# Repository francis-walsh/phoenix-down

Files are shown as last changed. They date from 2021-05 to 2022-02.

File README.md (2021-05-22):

# phoenix-down



Phoenix Down is a PWM-controlled hot plate that regulates the temperature of your morning coffee. A 12V 2A voltage source is regulated by a buck converter to deliver a maximum of 24W to the array of power resistors, heating the board to a specified temperature monitored by a thermistor. The design uses a schmitt trigger, astable multivibrator, and a thermistor to configure the duty cycle of the PWM.

The computer has population options for different thermistors and voltage references for configuring the thermistor voltage threshold.

Rev 1 schematic
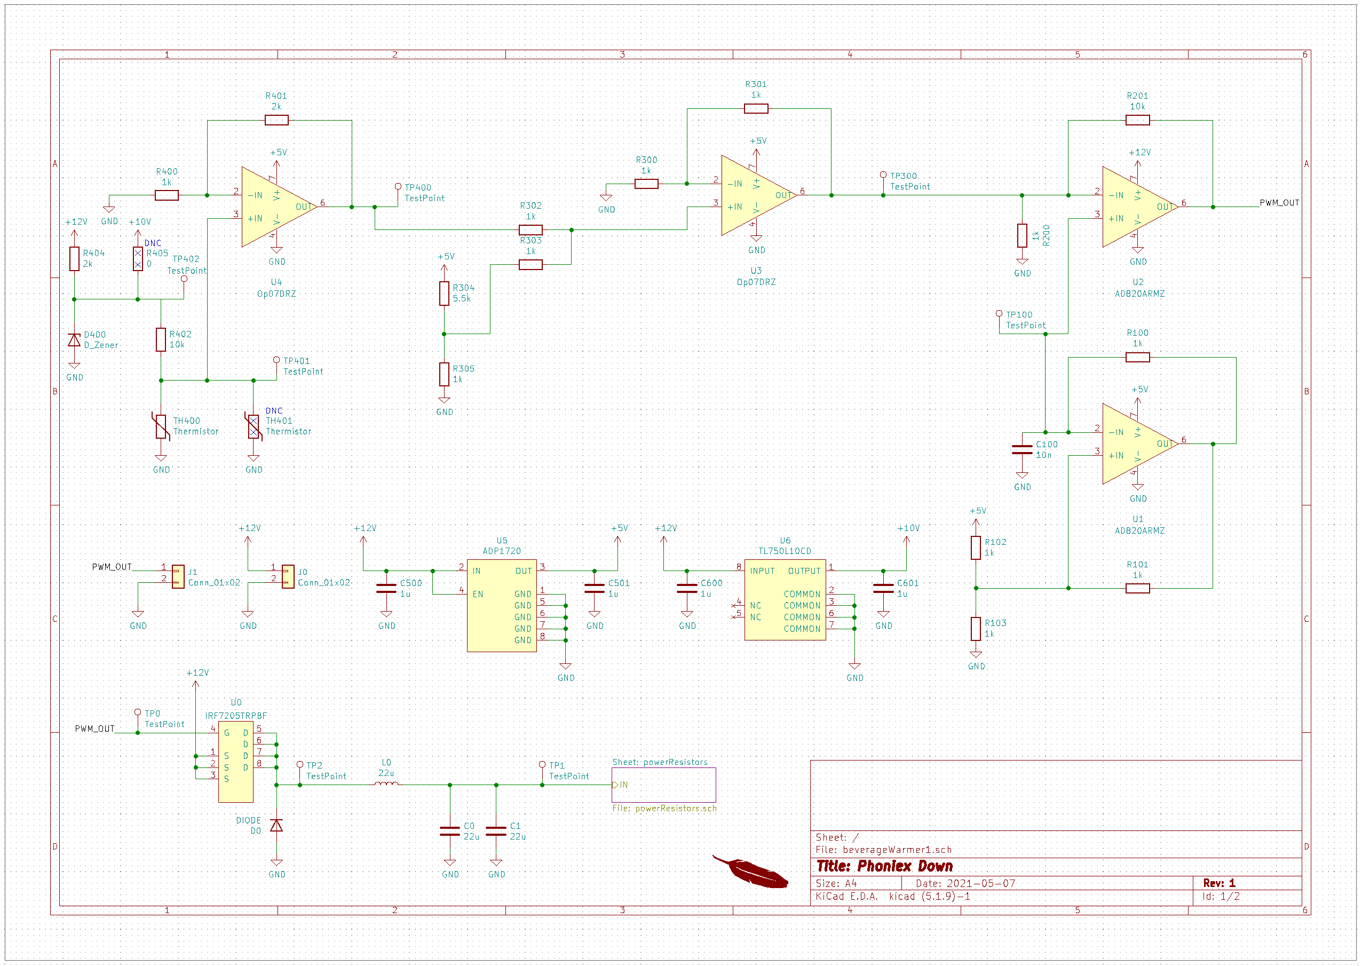
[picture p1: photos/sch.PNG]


Rev 1 TLspice simulation
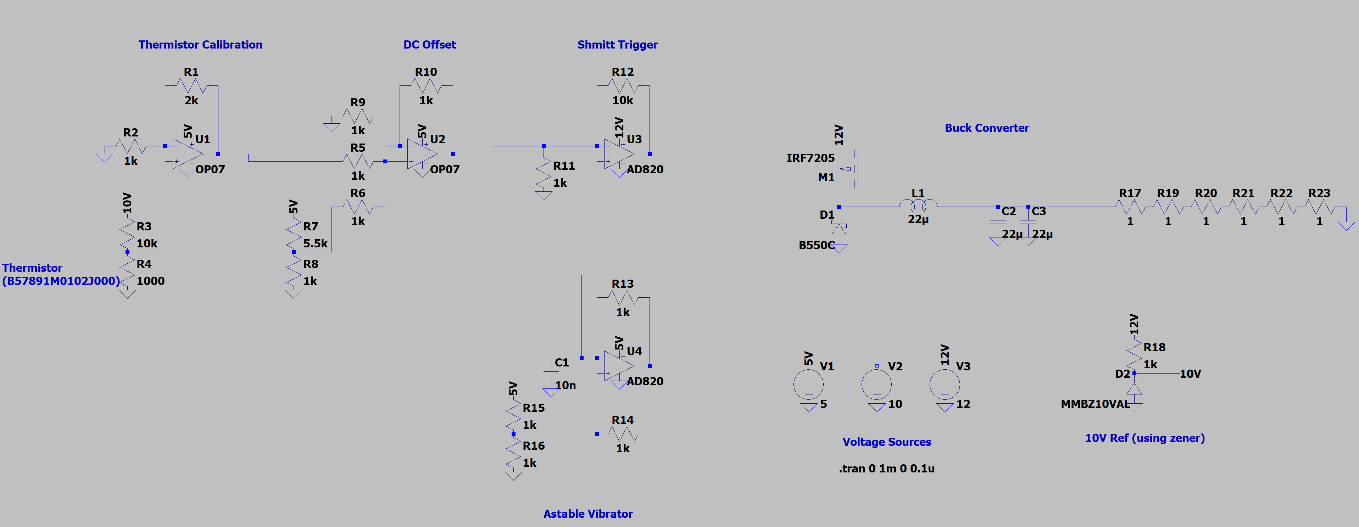
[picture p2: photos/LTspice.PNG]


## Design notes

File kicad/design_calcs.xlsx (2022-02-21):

Thermistor Properties
Parameter | Value | Unit
Standard Res | 10000 | Ohm
Beta | 3380 |  | Temp © | Temp (K) | Resistance (Ohm) | Low Res Parll. Combo (Ohm) | Divider Output (V) | ADC reading (Decimal) | Step For 2 deg change (V) | Temp Approx in Code © | Error %
Ref Temp | 25 | C | 20 | 293.15 | 12133.17001 | 5481.894371 | 2.132807912 | 2647.267033 |  | 20 | -7.105427358e-14
Ref Temp | 298.15 | K | 22 | 295.15 | 11221.29948 | 5287.753226 | 2.105466363 | 2613.330371 | 0.02734154872 | 21.61731737 | 1.739466488
Divider Properties |  |  | 24 | 297.15 | 10388.88114 | 5095.365983 | 2.077078143 | 2578.094568 | 0.02838822029 | 23.29654785 | 2.931050635
Parameter | Value | Unit | 26 | 299.15 | 9628.131096 | 4905.271444 | 2.047671086 | 2541.594173 | 0.02940705684 | 25.03604492 | 3.707519547
High Res | 3000 | Ohm | 28 | 301.15 | 8932.106405 | 4717.96757 | 2.017278881 | 2503.870999 | 0.03039220553 | 26.83381587 | 4.164943333
Low Res | 10000 | Ohm | 30 | 303.15 | 8294.606244 | 4533.908045 | 1.985940957 | 2464.973987 | 0.03133792423 | 28.68752832 | 4.374905609
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

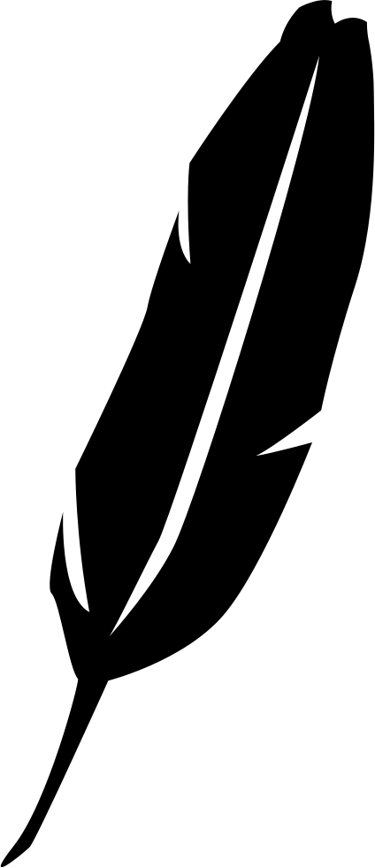
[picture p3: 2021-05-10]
kicad/downFeather/SeekPng.com_feather-vector-png_1046109.png

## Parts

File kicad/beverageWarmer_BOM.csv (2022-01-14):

Item | Qty | Reference(s) | Value | Digi | Have | Power | Tolerance | Voltage
1 | 30 | C1, C5, C6, C7, C8, C9, C15, C16, C19 | 1u | 445-6931-1-ND |  |  |  | 16V
2 | 25 | C2, C3, C10, C11, C12, C13, C14, C17, C18, C20 | 0.1u | 1276-1019-1-ND |  |  |  | 16V
3 | 5 | C4 | 10u | 1276-6641-1-ND |  |  |  | 6.3V
4 | 10 | D1, D5, D6 | V3FL45 | V3FL45HM3/HGICT-ND
5 | 4 | D2 | 5.6V | DDZ5V6BDICT-ND
6 | 4 | D3 | RED | 754-1123-1-ND
7 | 4 | D4 | GREEN | 754-1357-1-ND
8 | 10 | F1 | 3A | P15118CT-ND
9 | 4 | FB1 | FB | 490-1015-1-ND
10 | 2 | J1 | POWER | WM1860-ND
11 | 2 | J2 | CAN_CONN | WM1860-ND
12 | 3 | J3 | SWD | S9015E-03-ND
13 | 1 | J4 | THERM_CONN | WM1860-ND
14 | 3 | L1 | 68uH | SRR1260-560MCT-ND
15 | 9 | Q1, Q4 | Q_PMOS_DGS | SISS05DN-T1-GE3CT-ND
16 | 40 | R1, R3, R4, R5, R6, R7, R11, R12, R14, R15, R16, R17, R18, R20, R27, R29 | 1k | RMCF0603JJ1K00CT-ND |  |  | 1%
17 | 10 | R2, R19, R28 | 3k | RMCF0603FT3K00CT-ND |  |  | 1%
18 | 10 | R8 | 270 | A130470CT-ND |  | 1/4W
19 | 10 | R9 | 30 | 2019-RK73H2ATTD30R0FCT-ND |  | 1/4W
20 | 10 | R10, R25 | 10 | A130079CT-ND
21 | 10 | R13 | 120 | A129677CT-ND
22 | 10 | R21 | 10k | RMCF0603FT1K00CT-ND |  |  | 1%
23 | 10 | R22, R23, R24, R26 | 0 | 2019-RK73Z1JTTDCT-ND
24 | 20 | R30, R31, R32, R33, R34, R35 | 1 | A143800CT-ND
25 | 2 | SW1 | RESET | SW1020CT-ND
26 | 2 | SW2 | USER | SW1020CT-ND
27 | 3 | U1 | STM32F103TBU | 497-18758-1-ND | Yes
28 | 3 | U2 | MIC5283-3.3ML-TR | MIC5283-3.3YML-CT-ND | Yes
29 | 5 | U3 | Op07DRZ | OP07DRZ-ND | Yes
30 | 10 | U4 | TL391B | 296-TL391BIDBVRCT-ND
31 | 3 | U5 | SN65HVD232 | 296-12282-5-ND | Yes
32 | 10 | U6 | MCP1402T-E | MCP1402T-E/OTCT-ND

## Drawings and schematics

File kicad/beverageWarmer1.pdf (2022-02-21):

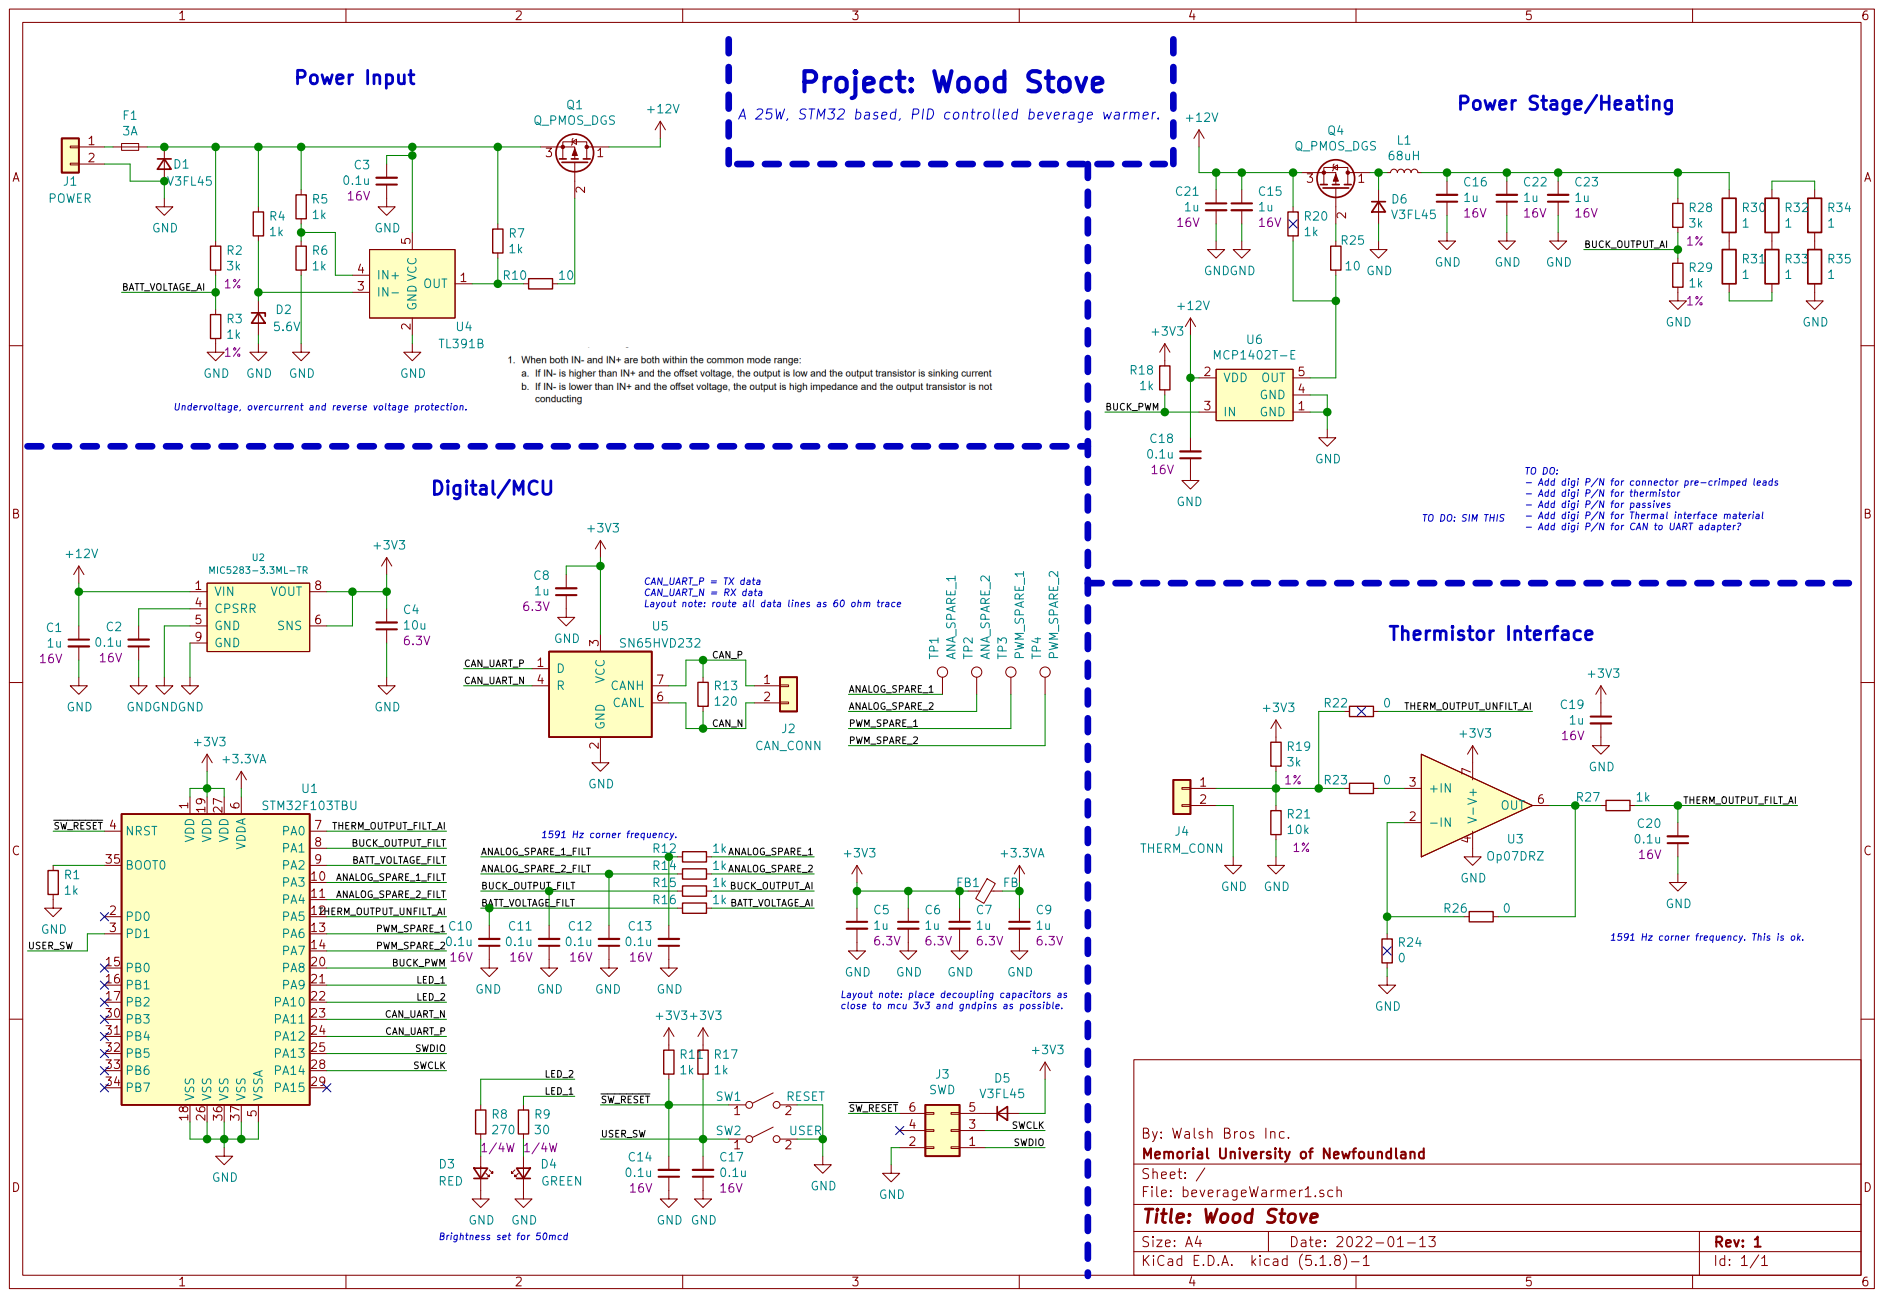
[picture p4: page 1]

1591 Hz corner frequency. This is ok. 1591 Hz corner frequency. Power Input

Layout note: route all data lines as 60 ohm trace Project: Wood Stove

TO DO: SIM THIS Digital/MCU

TO DO: - Add digi P/N for connector pre-crimped leads

- Add digi P/N for thermistor - Add digi P/N for passives - Add digi P/N for Thermal interface material - Add digi P/N for CAN to UART adapter?

By: Walsh Bros Inc. 1

1 PA3 10 PA4 11 PA5 12 PA6 13 PA7 14 PB0 15 PB1 16 PB2 17 VSS 18 VDD 19 PD0 2 PA8 20 PA9 21 PA10 22 PA11 23 PA12 24 PA13 25 VSS 26 VDD 27 PA14 28 PA15 29 PD1 3 PB3 30 PB4 31 PB5 32 PB6 33 PB7 34 BOOT0 35 VSS 36 VSS 37 NRST 4 VSSA

Layout note: place decoupling capacitors as close to mcu 3v3 and gndpins as possible.

File: beverageWarmer1.sch Sheet: / Memorial University of Newfoundland

Id: 1/1 Title: Wood Stove

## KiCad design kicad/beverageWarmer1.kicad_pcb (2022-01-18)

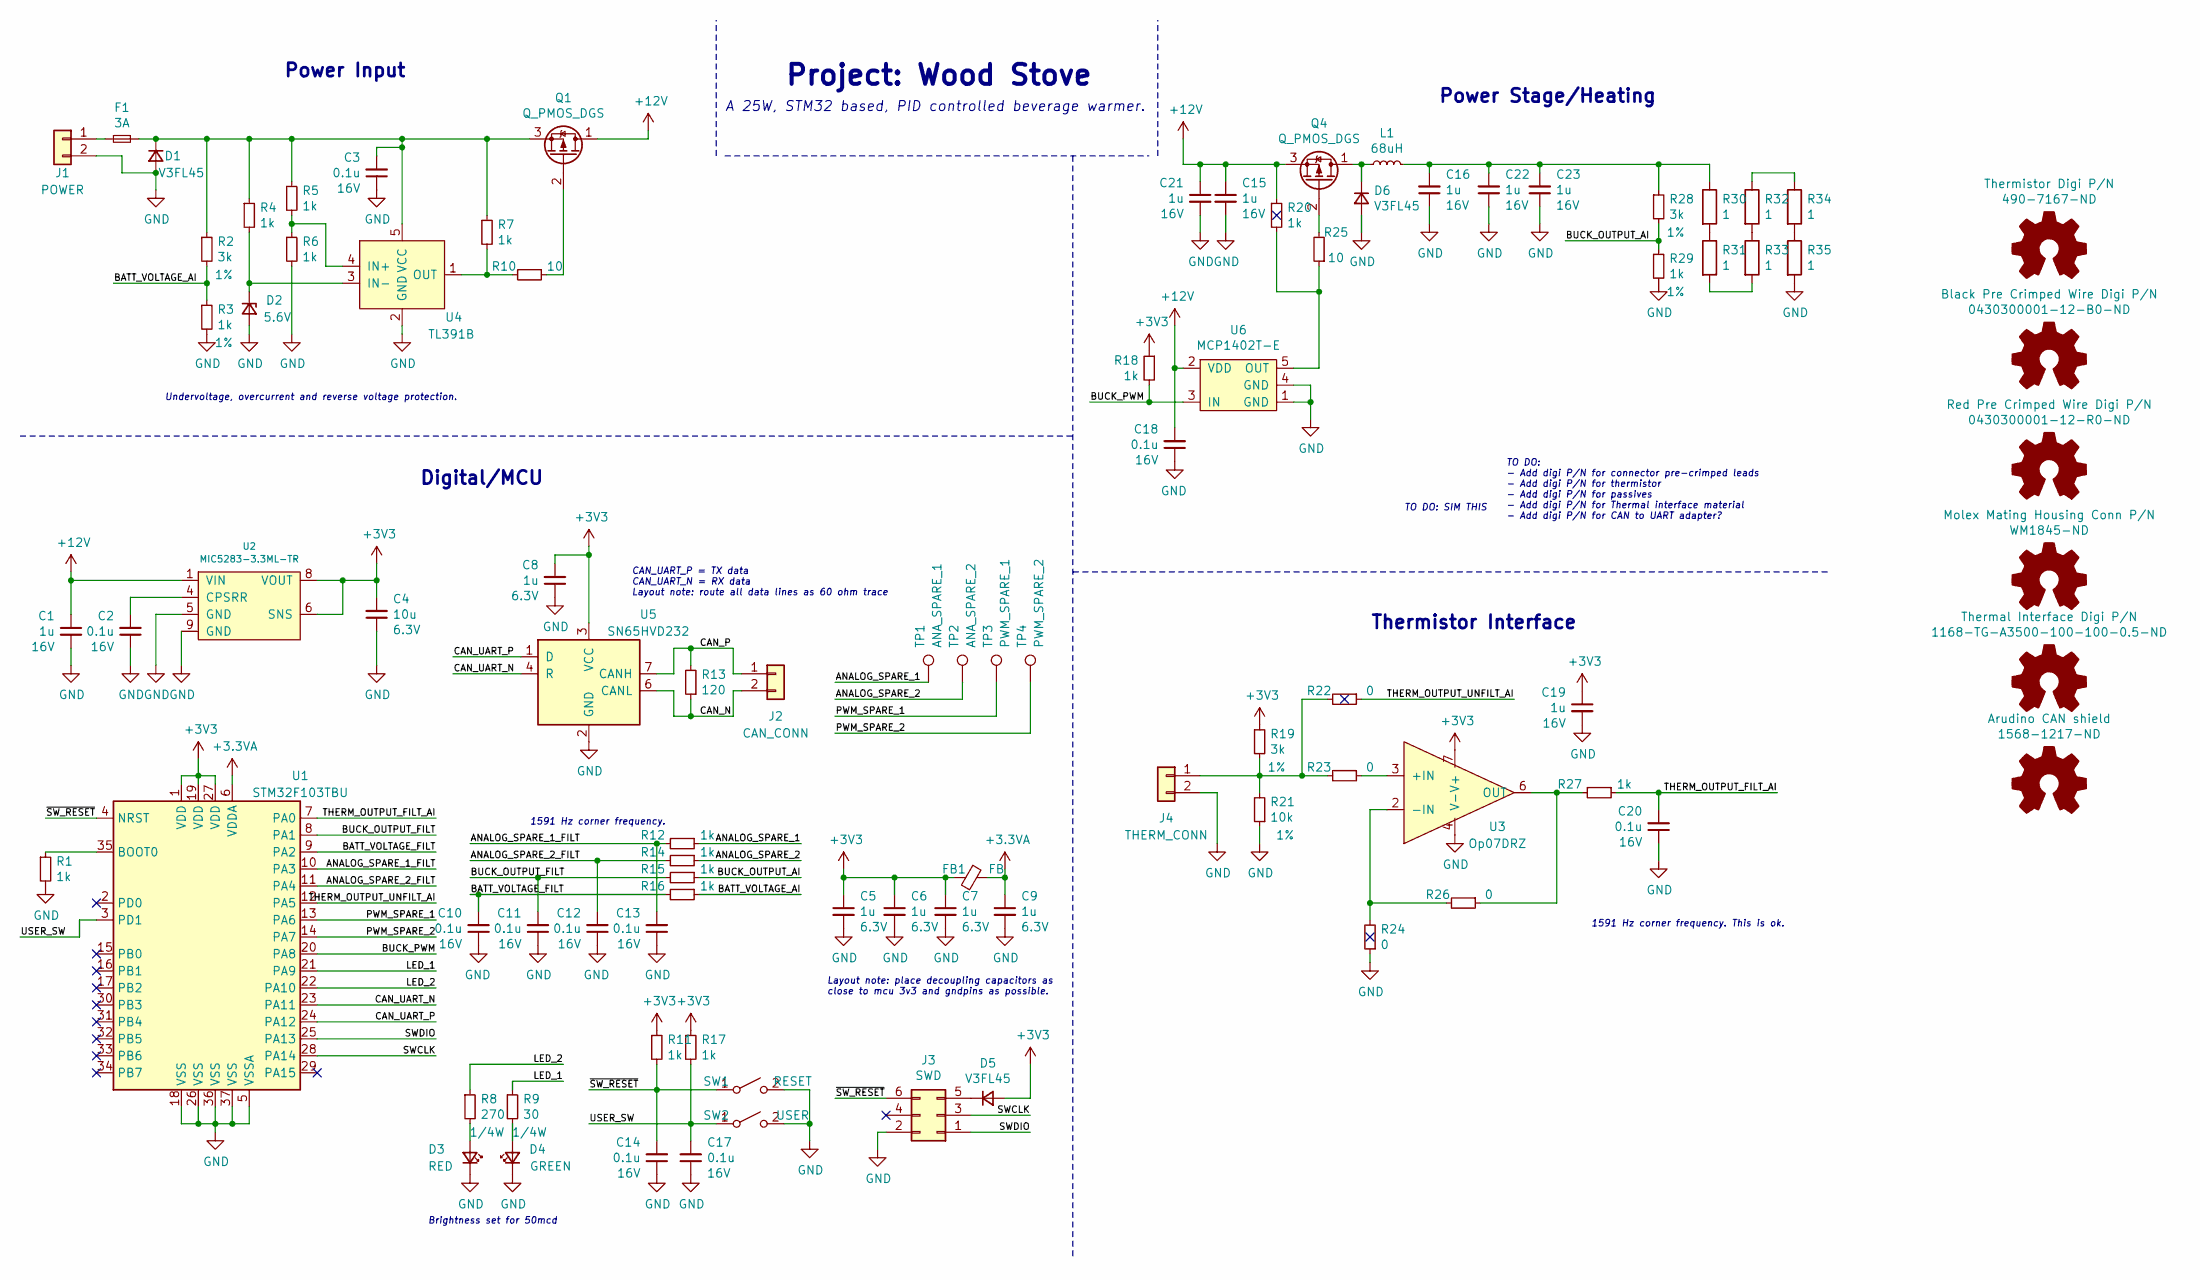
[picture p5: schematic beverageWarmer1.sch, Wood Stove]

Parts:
C1, C15, C16, C19, C21, C22, C23: 1u; C_0603_1608Metric; Voltage 16V; Digi 445-6931-1-ND
C2, C3, C10, C11, C12, C13, C14, C17, C18, C20: 0.1u; C_0603_1608Metric; Voltage 16V; Digi 1276-1019-1-ND
C4: 10u; C_1206_3216Metric; Voltage 6.3V; Digi 1276-6641-1-ND
C5, C6, C7, C8, C9: 1u; C_0603_1608Metric; Voltage 6.3V
D1, D5, D6: V3FL45; D_SMF; Digi V3FL45HM3/HGICT-ND
D2: 5.6V; D_SOD-123; Digi DDZ5V6BDICT-ND
D3: RED; LED_0603_1608Metric; Digi 754-1123-1-ND
D4: GREEN; LED_0603_1608Metric; Digi 754-1357-1-ND
F1: 3A; Fuse_0603_1608Metric; Digi P15118CT-ND
FB1: FB; L_0603_1608Metric; Digi 490-1015-1-ND
J1: POWER; Molex_Micro-Fit_3.0_43650-0200_1x02_P3.00mm_Horizontal; Digi WM1860-ND
J2: CAN_CONN; Molex_Micro-Fit_3.0_43650-0200_1x02_P3.00mm_Horizontal; Digi WM1860-ND
J3: SWD; PinSocket_2x03_P1.27mm_Vertical; Digi S9015E-03-ND
J4: THERM_CONN; Molex_Micro-Fit_3.0_43650-0200_1x02_P3.00mm_Horizontal; Digi WM1860-ND
L1: 68uH; L_Bourns_SRR1260; Digi SRR1260-560MCT-ND
Q1, Q4: Q_PMOS_DGS; SISS05DN-T1-GE3; Digi SISS05DN-T1-GE3CT-ND
R1, R4, R5, R6, R7, R11, R12, R14, R15, R16, R17, R18, R20, R27: 1k; R_0603_1608Metric; Digi RMCF0603JJ1K00CT-ND
R2, R19, R28: 3k; R_0603_1608Metric; Tolerance 1%; Digi RMCF0603FT3K00CT-ND
R3, R29: 1k; R_0603_1608Metric; Tolerance 1%; Digi RMCF0603FT1K00CT-ND
R8: 270; R_0805_2012Metric; Digi A130470CT-ND
R9: 30; R_0805_2012Metric; Digi 2019-RK73H2ATTD30R0FCT-ND
R10, R25: 10; R_0603_1608Metric; Digi A130079CT-ND
R13: 120; R_0603_1608Metric; Digi A129677CT-ND
R21: 10k; R_0603_1608Metric; Tolerance 1%; Digi RMCF0603FT1K00CT-ND
R22, R23, R24, R26: 0; R_0603_1608Metric; Digi 2019-RK73Z1JTTDCT-ND
R30, R32, R33, R34, R35: 1; 4320_SMD_RES; Digikey A143800CT-ND
R31: 1; 4320_SMD_RES; Digi A143800CT-ND
SW1: RESET; SW_SPST_B3U-1000P; Digi SW1020CT-ND
SW2: USER; SW_SPST_B3U-1000P; Digi SW1020CT-ND
TP1: ANA_SPARE_1; TestPoint_Pad_D1.0mm
TP2: ANA_SPARE_2; TestPoint_Pad_D1.0mm
TP3: PWM_SPARE_1; TestPoint_Pad_D1.0mm
TP4: PWM_SPARE_2; TestPoint_Pad_D1.0mm
U1: STM32F103TBU; QFN-36-1EP_6x6mm_P0.5mm_EP4.1x4.1mm; Digi 497-18758-1-ND
U2: MIC5283-3.3ML-TR; DFN-8-1EP_3x3mm_P0.65mm_EP1.55x2.4mm; Digi MIC5283-3.3YML-CT-ND
U3: Op07DRZ; SOIC-8_3.9x4.9mm_P1.27mm; Digikey OP07DRZ-ND
U4: TL391B; SOT-23-5; Digi 296-TL391BIDBVRCT-ND
U5: SN65HVD232; SOIC-8_3.9x4.9mm_P1.27mm; Digi 296-12282-5-ND
U6: MCP1402T-E; SOT-23-5; Digi MCP1402T-E/OTCT-ND

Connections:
+3.3VA: C9.1, FB1.1, U1.6 (VDDA)
+3V3: C4.2, C5.1, C6.1, C7.1, C8.2, C19.1, D5.2 (A), FB1.2, R11.1, R17.1, R18.1, R19.1, U1.1 (VDD), U1.19 (VDD), U1.27 (VDD), U2.6 (SNS), U2.8 (VOUT), U3.7 (V+), U5.3 (VCC)
+12V: C1.1, C15.1, C18.2, C21.1, Q1.1 (D), Q4.3 (S), R20.1, U2.1 (VIN), U6.2 (VDD)
/ANALOG_SPARE_1: R12.1, TP1.1
/ANALOG_SPARE_1_FILT: C13.2, R12.2, U1.10 (PA3)
/ANALOG_SPARE_2: R14.1, TP2.1
/ANALOG_SPARE_2_FILT: C12.2, R14.2, U1.11 (PA4)
/BATT_VOLTAGE_AI: R2.2, R3.1, R16.1
/BATT_VOLTAGE_FILT: C10.2, R16.2, U1.9 (PA2)
/BUCK_OUTPUT_AI: R15.1, R28.2, R29.1
/BUCK_OUTPUT_FILT: C11.2, R15.2, U1.8 (PA1)
/BUCK_PWM: R18.2, U1.20 (PA8), U6.3 (IN)
/CAN_N: J2.2, R13.1, U5.6 (CANL); also elsewhere on the board
/CAN_P: J2.1, R13.2, U5.7 (CANH); also elsewhere on the board
/CAN_UART_N: U1.23 (PA11), U5.4 (R)
/CAN_UART_P: U1.24 (PA12), U5.1 (D)
/LED_1: R9.1, U1.21 (PA9)
/LED_2: R8.1, U1.22 (PA10)
/PWM_SPARE_1: TP3.1, U1.13 (PA6)
/PWM_SPARE_2: TP4.1, U1.14 (PA7)
/SWCLK: J3.3, U1.28 (PA14); also elsewhere on the board
/SWDIO: J3.1, U1.25 (PA13); also elsewhere on the board
/THERM_OUTPUT_FILT_AI: C20.2, R27.1, U1.7 (PA0)
/THERM_OUTPUT_UNFILT_AI: R22.1, U1.12 (PA5)
/USER_SW: C17.2, R17.2, SW2.1 (A), U1.3 (PD1); also elsewhere on the board
/~SW_RESET: C14.2, J3.6, R11.2, SW1.1 (A), U1.4 (NRST); also elsewhere on the board
GND: C1.2, C2.1, C3.1, C4.1, C5.2, C6.2, C7.2, C8.1, C9.2, C10.1, C11.1, C12.1, C13.1, C14.1, C15.2, C16.1, C17.1, C18.1, C19.2, C20.1, C21.2, C22.1, C23.1, D1.2 (A), D2.2 (A), D3.1 (K), D4.1 (K), D6.2 (A), J1.2, J3.2, J4.2, R1.2, R3.2, R6.2, R21.1, R24.1, R29.2, R35.2, SW1.2 (B), SW2.2 (B), U1.5 (VSSA), U1.18 (VSS), U1.26 (VSS), U1.36 (VSS), U1.37 (VSS), U2.5 (GND), U2.9 (GND), U3.4 (V-), U4.2 (GND), U5.2 (GND), U6.1 (GND), U6.4 (GND); also elsewhere on the board
unnamed: C2.2, U2.4 (CPSRR)
unnamed: C3.2, D1.1 (K), F1.2, Q1.3 (S), R2.1, R4.1, R5.1, R7.1, U4.5 (VCC)
unnamed: C16.2, C22.2, C23.2, L1.2, R28.1, R30.1
unnamed: D2.1 (K), R4.2, U4.3 (IN-)
unnamed: D3.2 (A), R8.2
unnamed: D4.2 (A), R9.2
unnamed 33: D5.1 (K), J3.5; also elsewhere on the board
unnamed: D6.1 (K), L1.1, Q4.1 (D)
unnamed 35: F1.1, J1.1; also elsewhere on the board
unnamed 37: J4.1, R19.2, R21.2, R22.2, R23.2; also elsewhere on the board
unnamed: Q1.2 (G), R10.1
unnamed: Q4.2 (G), R25.2
unnamed: R1.1, U1.35 (BOOT0)
unnamed: R5.2, R6.1, U4.4 (IN+)
unnamed: R7.2, R10.2, U4.1 (OUT)
unnamed: R20.2, R25.1, U6.5 (OUT)
unnamed: R23.1, U3.3 (+IN)
unnamed: R24.2, R26.2, U3.2 (-IN)
unnamed: R26.1, R27.2, U3.6 (OUT)
unnamed: R30.2, R31.1
unnamed: R31.2, R33.2
unnamed: R32.1, R34.1
unnamed: R32.2, R33.1
unnamed: R34.2, R35.1

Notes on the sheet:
Layout note: place decoupling capacitors as close to mcu 3v3 and gndpins as possible.
TO DO: SIM THIS
1591 Hz corner frequency. This is ok.
Undervoltage, overcurrent and reverse voltage protection.
Thermistor Interface
Digital/MCU
Power Input
Power Stage/Heating
Project: Wood Stove
A 25W, STM32 based, PID controlled beverage warmer.
CAN_UART_P = TX data CAN_UART_N = RX data Layout note: route all data lines as 60 ohm trace
TO DO: - Add digi P/N for connector pre-crimped leads - Add digi P/N for thermistor - Add digi P/N for passives - Add digi P/N for Thermal interface material - Add digi P/N for CAN to UART adapter?
1591 Hz corner frequency.
Brightness set for 50mcd

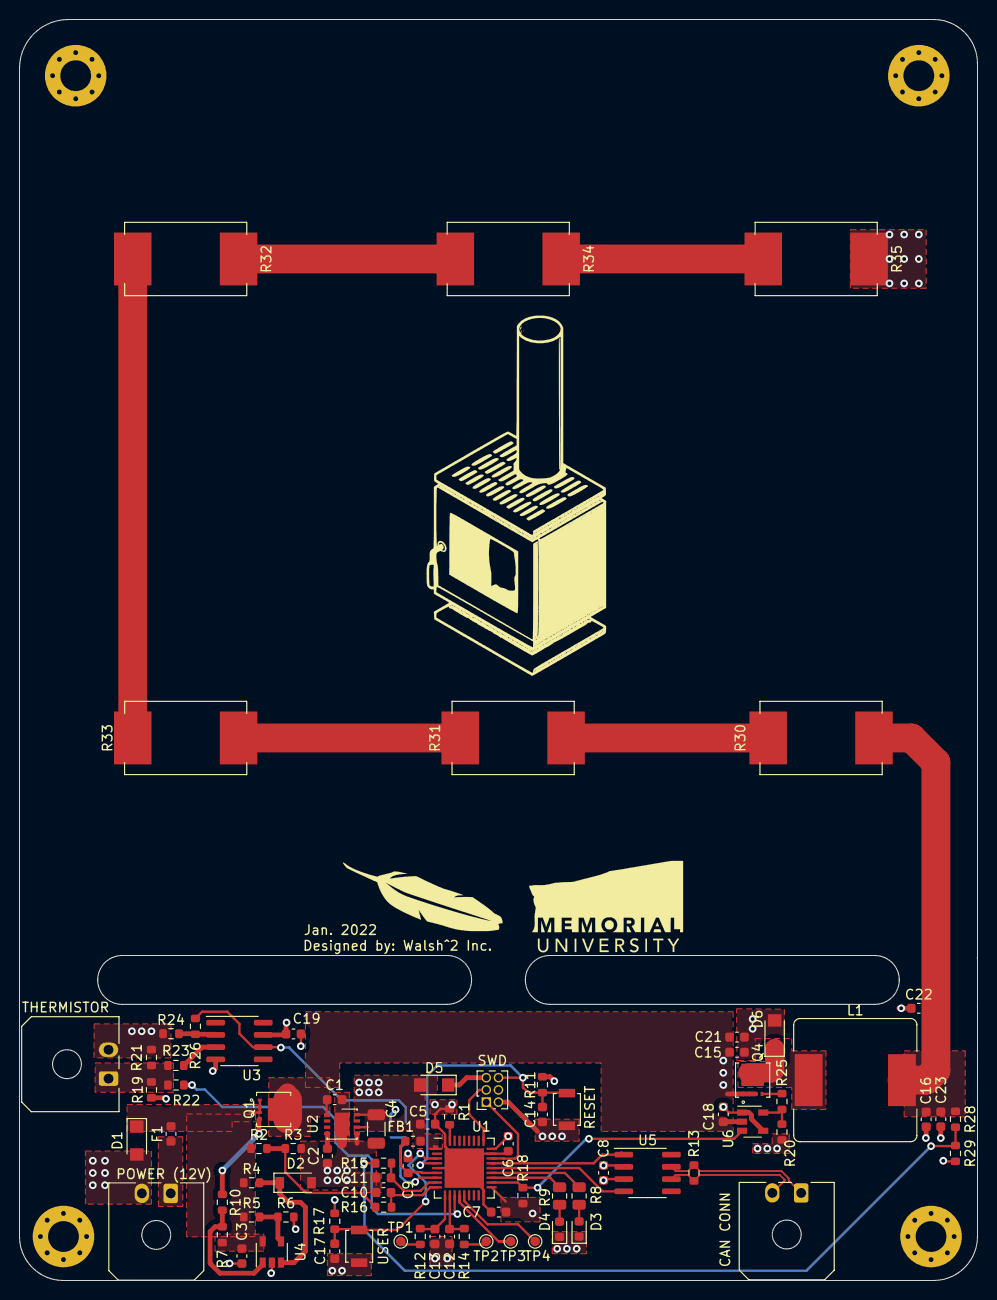
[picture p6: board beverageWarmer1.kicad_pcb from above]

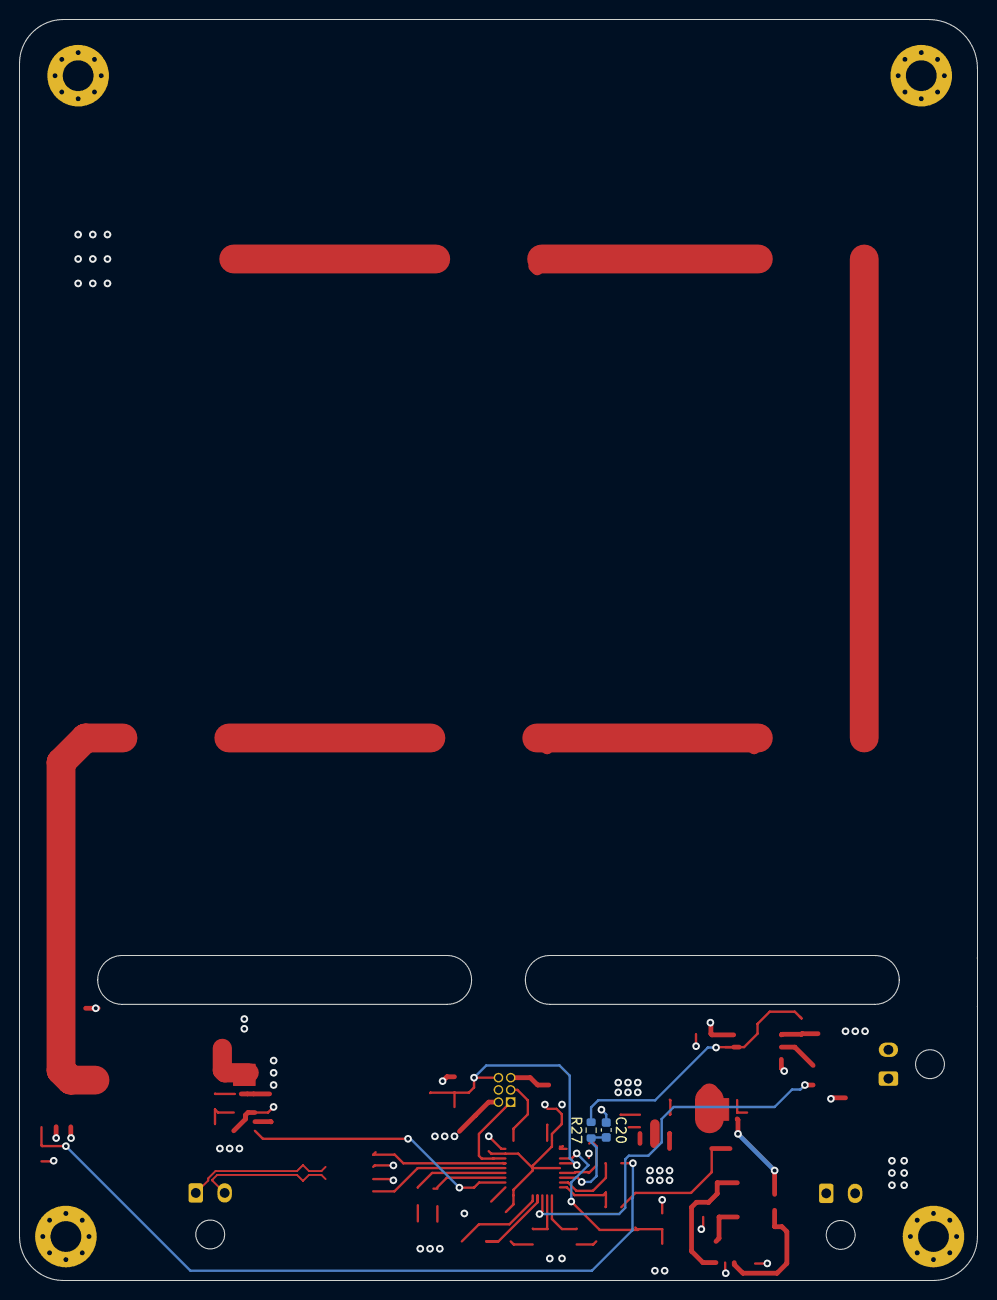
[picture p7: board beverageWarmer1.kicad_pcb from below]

Board: 4 copper layers, 99.6 x 131.1 mm, 85 parts (2 on the bottom side), 51 nets.

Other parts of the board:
CAN CONN: CAN_CONN; Molex_Micro-Fit_3.0_43650-0200_1x02_P3.00mm_Horizontal
POWER (12V): POWER; Molex_Micro-Fit_3.0_43650-0200_1x02_P3.00mm_Horizontal
RESET: RESET; SW_SPST_B3U-1000P
SWD: SWD; PinSocket_2x03_P1.27mm_Vertical
THERMISTOR: THERM_CONN; Molex_Micro-Fit_3.0_43650-0200_1x02_P3.00mm_Horizontal
USER: USER; SW_SPST_B3U-1000P

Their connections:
/CAN_N: CAN CONN.2; also elsewhere on the board
/CAN_P: CAN CONN.1; also elsewhere on the board
/SWCLK: SWD.3; also elsewhere on the board
/SWDIO: SWD.1; also elsewhere on the board
/USER_SW: USER.1; also elsewhere on the board
/~SW_RESET: RESET.1, SWD.6; also elsewhere on the board
GND: POWER (12V).2, RESET.2, SWD.2, THERMISTOR.2, USER.2; also elsewhere on the board
unnamed 33: SWD.5; also elsewhere on the board
unnamed 35: POWER (12V).1; also elsewhere on the board
unnamed 37: THERMISTOR.1; also elsewhere on the board

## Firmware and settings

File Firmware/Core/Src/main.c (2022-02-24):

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
/* Includes ------------------------------------------------------------------*/
#include "main.h"

/* USER CODE BEGIN Includes */
#include "PID.h"
/* USER CODE END Includes */

ADC_HandleTypeDef hadc1;

CAN_HandleTypeDef hcan;

TIM_HandleTypeDef htim1;
TIM_HandleTypeDef htim2;

void SystemClock_Config(void);
static void MX_GPIO_Init(void);
static void MX_ADC1_Init(void);
static void MX_CAN_Init(void);
static void MX_TIM1_Init(void);
static void MX_TIM2_Init(void);
/* USER CODE BEGIN 0 */
int duty = 0;
int direction = 1;

// CAN Vars
uint8_t datacheck = 0;
uint8_t RxData[8];


// ADC variables
uint16_t therm_val;
uint8_t therm_val_bytes[2];
float fThermTemp = 0.0f;
float thermSlope = -59.152358f;
float thermOffset = 146.160f;

uint16_t buck_voltage;
uint8_t buck_voltage_bytes[2];

uint16_t batt_voltage;
uint8_t batt_voltage_bytes[2];

ADC_ChannelConfTypeDef sConfig = {0};

// PID Parameters
/* Controller parameters */
float setpoint = 35.0f;

#define PID_KP  20.0f
#define PID_KI  1.0f
#define PID_KD  0.0f

#define PID_TAU 0.02f

#define PID_LIM_MIN  0.0f
#define PID_LIM_MAX  95.0f

#define PID_LIM_MIN_INT -5.0f
#define PID_LIM_MAX_INT  5.0f

#define SAMPLE_TIME_S 0.01f
float fNewDuty = 0.0f;
int newDuty = 0;

PIDController pid = {	PID_KP, PID_KI, PID_KD,
                       PID_TAU,
                       PID_LIM_MIN, PID_LIM_MAX,
						PID_LIM_MIN_INT, PID_LIM_MAX_INT,
                       SAMPLE_TIME_S };

/* USER CODE END 0 */

/**
  * @brief  The application entry point.
  * @retval int
  */
int main(void)
{
  /* MCU Configuration--------------------------------------------------------*/

  /* Reset of all peripherals, Initializes the Flash interface and the Systick. */
  HAL_Init();

  /* Configure the system clock */
  SystemClock_Config();

  /* Initialize all configured peripherals */
  MX_GPIO_Init();
  MX_ADC1_Init();
  MX_CAN_Init();
  MX_TIM1_Init();
  MX_TIM2_Init();
  /* USER CODE BEGIN 2 */
  HAL_TIM_PWM_Start(&htim1, TIM_CHANNEL_1);
  HAL_TIM_Base_Start_IT(&htim2);

  HAL_CAN_Start(&hcan);
  if(HAL_CAN_ActivateNotification(&hcan, CAN_IT_RX_FIFO0_MSG_PENDING) != HAL_OK)
  {
	  Error_Handler();
  }

  PIDController_Init(&pid);


  /* USER CODE END 2 */

  /* Infinite loop */
  /* USER CODE BEGIN WHILE */

  while (1)
  {
	//TIM1->CCR1 = 9999;

	// sendCANMessage();

	HAL_Delay(500);



	if(datacheck == 1)
	{
		HAL_GPIO_TogglePin(GPIOA, LED_2_Pin);
		HAL_Delay(300);
		datacheck = 0;
		setpoint = RxData[0];
	}

    /* USER CODE END WHILE */

    /* USER CODE BEGIN 3 */
  }
  /* USER CODE END 3 */
}

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
/* USER CODE BEGIN 4 */

// Callback: timer has rolled over
void HAL_TIM_PeriodElapsedCallback(TIM_HandleTypeDef *htim)
{
  // Check which version of the timer triggered this callback and toggle LED
  if (htim == &htim2)
  {
    HAL_GPIO_TogglePin(GPIOA, LED_2_Pin);
	getADCData();
	fNewDuty = PIDController_Update(&pid, setpoint, fThermTemp);
	newDuty = (int)fNewDuty;
	//TIM1->CCR1 = ((PID_LIM_MAX - newDuty)/2);
  }
}

void sendCANMessage()
{

	// Thermistor reading
	uint32_t mb;
	CAN_TxHeaderTypeDef msg;
	msg.StdId = 120;
	msg.IDE = CAN_ID_STD;
	msg.RTR = CAN_RTR_DATA;
	msg.DLC = 2;
	msg.TransmitGlobalTime = DISABLE;

	if (HAL_CAN_AddTxMessage(&hcan, &msg, therm_val_bytes, &mb) != HAL_OK)
	{
		Error_Handler();
	}

	//HAL_Delay(1);

	/* Buck Voltage
	//uint32_t mb1;
	CAN_TxHeaderTypeDef msg1;
	msg.StdId = 126;
	msg.IDE = CAN_ID_STD;
	msg.RTR = CAN_RTR_DATA;
	msg.DLC = 2;
	msg.TransmitGlobalTime = DISABLE;

	if (HAL_CAN_AddTxMessage(&hcan, &msg1, buck_voltage_bytes, &mb) != HAL_OK)
	{
		Error_Handler();
	}

	HAL_Delay(1);
	// Batt voltage
	//uint32_t mb2;
	CAN_TxHeaderTypeDef msg2;
	msg.StdId = 127;
	msg.IDE = CAN_ID_STD;
	msg.RTR = CAN_RTR_DATA;
	msg.DLC = 2;
	msg.TransmitGlobalTime = DISABLE;

	if (HAL_CAN_AddTxMessage(&hcan, &msg2, batt_voltage_bytes, &mb) != HAL_OK)
	{
		Error_Handler();
	}
	*/
}


// CAN read function
CAN_RxHeaderTypeDef   RxHeader;



void HAL_CAN_RxFifo0MsgPendingCallback(CAN_HandleTypeDef *hcan)
{

  if (HAL_CAN_GetRxMessage(hcan, CAN_RX_FIFO0, &RxHeader, RxData) != HAL_OK)
  {
    Error_Handler();
  }

  if ((RxHeader.DLC == 1))
  {
	  datacheck = 1;

  }
}

void getADCData()
{
	sConfig.Channel = ADC_CHANNEL_0;
	HAL_ADC_ConfigChannel(&hadc1, &sConfig);
    HAL_ADC_Start(&hadc1);
    HAL_ADC_PollForConversion(&hadc1, HAL_MAX_DELAY);
    therm_val = HAL_ADC_GetValue(&hadc1);
	therm_val_bytes[0] = (uint8_t)(therm_val >> 8);
	therm_val_bytes[1] = (uint8_t)therm_val;
	fThermTemp = (float)therm_val*3.3/4095.0;
	fThermTemp = fThermTemp * thermSlope + thermOffset;
}


void sweepBuckDuty()
{
	if(direction == 1)
		{
			if(duty <= 15988)
			{
				duty+=2000;
				TIM1->CCR1 = duty;
			}
			if(duty >= 100)
			{
				direction = 0;
			}
		}

		if(direction == 0)
		{
			if(duty >= 0)
			{
				duty-=2000;
				TIM1->CCR1 = duty;
			}
			if(duty <= 0)
			{
				direction = 1;
			}
		}
}
/* USER CODE END 4 */
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


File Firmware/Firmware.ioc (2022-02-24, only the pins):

Mcu.UserName=STM32F103TBUx
PA0-WKUP.GPIO_Label=THERM_FILT_AI
PA0-WKUP.Signal=ADCx_IN0
PA1.GPIO_Label=BUCK_OUTPUT_FILT
PA1.Signal=ADCx_IN1
PA10.GPIO_Label=LED_2
PA10.Signal=GPIO_Output
PA11.Signal=CAN_RX
PA12.Signal=CAN_TX
PA13.Signal=SYS_JTMS-SWDIO
PA14.Signal=SYS_JTCK-SWCLK
PA2.GPIO_Label=BATT_VOLTAGE_FILT
PA2.Signal=ADCx_IN2
PA8.GPIO_Label=BUCK_PWM
PA8.Signal=S_TIM1_CH1
PA9.GPIO_Label=LED_1
PA9.Signal=GPIO_Output
PD1-OSC_OUT.GPIO_Label=USER_PB
PD1-OSC_OUT.Signal=GPXTI1

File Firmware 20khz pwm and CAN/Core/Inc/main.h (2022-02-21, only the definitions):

#define USER_PB_Pin GPIO_PIN_1
#define USER_PB_GPIO_Port GPIOD
#define THERM_FILT_AI_Pin GPIO_PIN_0
#define THERM_FILT_AI_GPIO_Port GPIOA
#define BUCK_OUTPUT_FILT_Pin GPIO_PIN_1
#define BUCK_OUTPUT_FILT_GPIO_Port GPIOA
#define BATT_VOLTAGE_FILT_Pin GPIO_PIN_2
#define BATT_VOLTAGE_FILT_GPIO_Port GPIOA
#define BUCK_PWM_Pin GPIO_PIN_8
#define BUCK_PWM_GPIO_Port GPIOA
#define LED_1_Pin GPIO_PIN_9
#define LED_1_GPIO_Port GPIOA
#define LED_2_Pin GPIO_PIN_10
#define LED_2_GPIO_Port GPIOA

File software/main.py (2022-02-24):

# Declare Imports
import serial
import time
import threading
import matplotlib.pyplot as plt
from playsound import playsound
import os
from datetime import datetime



# Declare Vars
# Plot init
plt.ion()
fig = plt.figure()
sample = []
timeElapsed = []
temperatureData = []
# Sample number
n = 0
maxYRange = 10
maxLength = 50
cropData = True
fancyYLim = True

# Thermistor values
dataBits = 12
VREF = float(3.3)
deltaV = float( VREF/pow(2, dataBits) )
thermistorSlope = float(-59.15236876) # Degrees per volt
thermistorOffset = float(146.1606401) # Degrees

# Values for alarm threshold
regulatedTemperature = 55
alarmThresholdMax = 70
alarmThresholdMin = 20

# Misc
saveLogDirectory = 'logs/'
os.system('cls')
print("Starting serial...")

# Serial init
ser = serial.Serial('com4', 9600)



# Declare functions
# Woodstove logo
def logo():
	print("---------------------Woodstove--------------------")
	print("**************************************************")
	print("                          ****                    ") 
	print("                       *        *                 ") 
	print("                       * ,****, *                 ") 
	print("                       *        *                 ") 
	print("                       *        *                 ") 
	print("                       *        *                 ") 
	print("                       *        *                 ") 
	print("                       *        *                 ") 
	print("                       *        *                 ") 
	print("                       *        *                 ") 
	print("                  *,   *        *                 ") 
	print("              *   ** *,*        *                 ") 
	print("          *   *,,* **  *        *                 ") 
	print("          * ** *. * ,* **,    *** , *,            ") 
	print("        **,   . ** */(/(**(**(, .*.**   .         ") 
	print("            ***    (**(*,(/ ** **    ****         ") 
	print("          .     ***     ** *,   ,********         ") 
	print("          *****      **     **** ********         ") 
	print("          *********      ***,************         ") 
	print("      *** ********    *.  .**************         ") 
	print("     **   ********     *  .**************         ") 
	print("     **.  ********     *  .**************         ") 
	print("     ***      ******,  *  .**************         ") 
	print("        .*  *     ,*****  .**************         ") 
	print("       ,   ***  *      ,  .*************          ") 
	print("        *,     ***  *     .**********   *         ") 
	print("            .*      ***  *.******     **          ") 
	print("                 *      *****    ,**              ") 
	print("                     *.      ***                  ") 
	print("                         ,*                       ") 
	print("**************************************************")
	print("By Walsh^2 Inc")
	print("Date ", datetime.now())
	print("Temperature is currently being regulated at " + str(regulatedTemperature))
	print("Alarm threshold is between " + str(alarmThresholdMin) + " and " + str(alarmThresholdMax) + " Degrees C")



def saveLog(name):
	print("Saving "+name+" in directory "+saveLogDirectory+"...")
	try:
		file = open(saveLogDirectory+name+".csv", 'x')
	except:
		file = open(saveLogDirectory+name+".csv", 'w')
	file.write("Date,"+str(datetime.now())+"\n")
	file.write("Sample (n),Elapsed Time (s),Temperature (Degrees C)\n")
	for i in range (0, len(sample)):
		file.write(str(sample[i])+","+str(timeElapsed[i])+","+str(temperatureData[i])+"\n")
	file.close()
	print("File saved!")



# Audible alarm function
def playAlarm(numberOfTimes):
	for i in range(0, numberOfTimes):
		playsound('peep.mp3')
		
	
# Send byte over serial
# Byte should be of the form 0x[XX]
def writeByte(byte):
	ser.write(bytes.fromhex(str(byte)))
	print(bytes.fromhex(str(byte)))



# Serial write thread
def commandThread():
	print("Enter 'help' or 'h' for a list of commands")
	while(True):
		temp = input("=>")
		
		
		
		# Example commands
		# Easter egg
		if(temp == "bird"):
			playAlarm(3)
			
		if(temp == "help" or temp == "h"):
			print("t					- Displays current temperature")
			print("setTemp [num]		- Sets target temperature to [num]")
			print("setMaxThreshold [num]- Sets maximum threshold for alarm to [num]")
			print("setMinThreshold [num]- Sets minimum threshold for alarm to [num]")
			print("sampleCrop			- Toggles x axis cropping")
			print("sampleLength [num]	- Sets the length of x axis to [num]")
			print("fancyLims			- Toggles y axis cropping")
			print("ping					- Arduino should respond with 'pong' if connected correctly")
			print("saveas [name]		- Saves the logged data in a csv file [name].csv")
			print("clr					- Clears terminal")
		
		
		if(temp == "t"):
			print(temperatureData[len(temperatureData)-1])
			
		if("setTemp" in temp):
			byteData = str(hex(int(temp.replace("setTemp ", ""))))[2:]
			if(len(byteData) <= 1):
				byteData = '0'+byteData
			writeByte(byteData)
			
		if(temp == "sampleCrop"):
			global cropData
			cropData = not cropData
		
		if("sampleLength" in temp):
			global maxLength
			maxLength = int(temp.replace("sampleLength ", ""))
		
		if(temp == "fancyLims"):
			global fancyYLim
			fancyYLim = not fancyYLim
		
		if("saveas" in temp):
			saveLog(temp.replace("saveas ", ""))
			
		if("setMinThreshold" in temp):
			global alarmThresholdMin
			alarmThresholdMin = int(temp.replace("setMinThreshold ", ""))
		
		if("setMaxThreshold" in temp):
			global alarmThresholdMax
			alarmThresholdMax = int(temp.replace("setMaxThreshold ", ""))
		
		if(temp == 'clr'):
			os.system('cls')
			logo()
			
		if(temp == "ping"):
			writeByte('FF')

		

# Start program here...
# Print logo
logo()
startTime = time.time()

# Start threads
p1 = threading.Thread(target=commandThread)
p1.start()
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

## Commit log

2021-05-10 Init Commit
    [beverageWarmer1-B_Cu.gbr, beverageWarmer1-B_Mask.gbr, beverageWarmer1-B_SilkS.gbr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]
2021-05-11 Added photos of schematic
2021-05-17 Fixed Spelling Mistake
    [beverageWarmer1.sch]
2021-05-22 Added PCBA image
    [beverageWarmer1.kicad_pcb]
2022-01-13 first push
    [beverageWarmer1-B_Cu.gbr, beverageWarmer1-B_Mask.gbr, beverageWarmer1-B_SilkS.gbr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]
2022-01-14 2nd commit
    changed gate drive for buck converter
    [beverageWarmer1.sch, design_calcs.xlsx]
2022-01-14 Final Sch Push?
    [beverageWarmer1.kicad_pcb, beverageWarmer1.sch, beverageWarmer_BOM.csv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]
2022-01-15 Preliminary Layout Complete
    [beverageWarmer1.kicad_pcb, beverageWarmer1.sch]
2022-01-17 Finished Layout
    [beverageWarmer1.kicad_pcb]
2022-01-17 Adjusted Silk Screen
    [beverageWarmer1.kicad_pcb]
2022-01-17 small ss and copper changes
    [beverageWarmer1.kicad_pcb, beverageWarmer1.sch]
2022-01-18 Hopefully the ordered gerbers
    [beverageWarmer1-B_Cu.gbr, beverageWarmer1-B_Mask.gbr, beverageWarmer1-B_Paste.gbr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]
2022-02-22 Added more functions to python script, and added arduino firmware
2022-02-24 daniel's broken temp set... probably just a binary formatting issue
    ... probably just a binary formatting issue
    [Firmware.ioc, main.c, main.py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]

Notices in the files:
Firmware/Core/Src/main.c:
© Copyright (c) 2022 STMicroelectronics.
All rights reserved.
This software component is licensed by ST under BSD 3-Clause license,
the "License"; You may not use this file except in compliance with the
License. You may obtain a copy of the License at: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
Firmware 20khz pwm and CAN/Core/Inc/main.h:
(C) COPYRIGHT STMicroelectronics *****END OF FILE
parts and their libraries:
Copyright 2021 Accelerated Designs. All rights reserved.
